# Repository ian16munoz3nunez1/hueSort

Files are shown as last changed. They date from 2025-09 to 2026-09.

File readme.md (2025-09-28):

# HueSort

## Bibliografía y referencias

- [Arduino Documentation](https://docs.arduino.cc/language-reference/)
- [Arduino `abs` function](https://docs.arduino.cc/language-reference/en/functions/math/abs/)
- [Arduino `map` function](https://docs.arduino.cc/language-reference/en/functions/math/map/)
- [`analogWrite` function](https://docs.arduino.cc/language-reference/en/functions/analog-io/analogWrite/)
- [`analogWriteResolution` function](https://docs.arduino.cc/language-reference/en/functions/analog-io/analogWriteResolution/)
- [esp32 repository](https://github.com/espressif/arduino-esp32)
- [esp32 Guidebook](https://espressif-docs.readthedocs-hosted.com/projects/arduino-esp32/en/latest/)
- [esp32 installation guide](https://docs.espressif.com/projects/arduino-esp32/en/latest/installing.html)
- [esp32 PWM](https://randomnerdtutorials.com/esp32-pwm-arduino-ide/)
- [How to create a WiFi Access Point with esp32](https://www.upesy.com/blogs/tutorials/how-create-a-wifi-acces-point-with-esp32#)
- [How do I transfer an image taken by esp32cam over sockets](https://stackoverflow.com/questions/57823528/how-do-i-transfer-an-image-taken-by-esp32-cam-over-sockets)
- [esp32cam ov2640 camera settings](https://randomnerdtutorials.com/esp32-cam-ov2640-camera-settings/)

- [API Pins](https://gpiozero.readthedocs.io/en/stable/api_pins.html)
- [Use GPIO from Python](https://www.raspberrypi.com/documentation/computers/os.html#use-gpio-from-python)
- [Generating PWM in Raspberry Pi](https://forums.raspberrypi.com/viewtopic.php?t=358623)
- [Raspberry Pi y PWM](https://www.prometec.net/raspberry-y-pwm/)
- [FreeRTOS y Raspberry Pi OS](https://forums-raspberrypi-com.translate.goog/viewtopic.php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)

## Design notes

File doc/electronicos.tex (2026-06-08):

\section{Módulo de Sistemas Electrónicos}

\subsection{Componentes utilizados}

{\justify
    \renewcommand{\labelitemi}{$\bullet$}
    \begin{itemize}
        \item Módulo de carga TP4056
        \item Motor CD motorreductor JGA25-370 6V
        \item Regulador de voltaje LM7805
        \item Transistor NPN TIP122
        \item Transistor PNP TIP127
        \item Diodo rectificador 1N4007
    \end{itemize}
}

\subsection{Divisor de voltaje}

{\justify
    \begin{equation*}
        I = \dfrac{V_{in}}{R_1 + R_2} \quad V_d = I R_2
    \end{equation*}

    \begin{equation*}
        V_d = \dfrac{V_{in}}{R_1 + R_2} R_2 \quad\rightarrow\quad V_d = \dfrac{V_{in} R_2}{R_1 + R_2}
    \end{equation*}

    \begin{equation*}
        V_d (R_1 + R_2) = V_{in} R_2 \quad\rightarrow\quad V_d R_1 + V_d R_2 = V_{in} R_2
    \end{equation*}

    \begin{equation*}
        V_d R_1 = V_{in} R_2 - V_d R_2 \quad\rightarrow\quad V_d R_1 = (V_{in} - V_d) R_2
    \end{equation*}

    \begin{equation*}
        R_1 = \dfrac{(V_{in} - V_d) R_2}{V_d} \quad\quad \dfrac{V_d R_1}{V_{in} - V_d} = R_2
    \end{equation*}
}

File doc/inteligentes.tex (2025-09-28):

\section{Módulo de Sistemas Inteligentes}

{\justify
    \hspace{0.5cm} Para el módulo de sistemas inteligentes se utilizó un
    \textbf{Perceptrón Multicapa} para la clasificación de color utilizando el sensor
    \textbf{TCS230} para esto, la red tiene 3 nodos de entrada para realizar la
    clasificación y fue entrenada con 600 muestras diferentes de colores.

    \hspace{0.5cm} Para comenzar, primero veremos el proceso básico utilizado para el
    \textbf{Perceptrón Simple}

}

\subsection{El Perceptrón Simple}
\begin{center}
    \begin{tikzpicture}[scale=0.6]
        \draw (0,4) -- node[above]{$w_1$} (4,0);
        \draw (0,2) -- node[above]{$w_2$} (4,0);
        \draw (0,0) -- node[above]{$w_3$} (4,0);
        \draw (0,-2) -- node[above]{$w_n$} (4,0);
        \draw (0,-4) -- node[above]{$b$} (4,0);
        \draw (4,0) -- node[above]{$v$} (7,0);
        \draw (7,0) -- (9,0);

        \foreach \i in {4,2,...,-4}{\fill[white] (0,\i) circle (5mm);}
        \fill[white] (9,0) circle (5mm);

        \node at (0,4){$x_1$};
        \node at (0,2){$x_2$};
        \node at (0,0){$x_3$};
        \node at (0,-2){$x_n$};
        \node at (0,-4){$+1$};
        \node at (9,0){$y$};

        \draw[color=black,fill=white] (4,0) circle (8mm);
        \node at (4,0){\Large $\sum$};

        \draw[color=black,fill=white] (7,0) circle (6mm);
        \node at (7,0){\Large $\varphi$};
    \end{tikzpicture}
\end{center}

{\justify
    \hspace{0.5cm} Primero de tiene la ecuación en la que interactuan los patrones de
    entrada con los pesos sinápticos y el \textbf{bias}, que se puede representar de
    diferentes formas, como

    \begin{equation}
        v = \sum_{i=1}^p [w_i x_i] + b
    \end{equation}

    \begin{equation}
        v =
        \begin{bmatrix}
            w_1 & w_2 & \cdots & w_p
        \end{bmatrix}
        \begin{bmatrix}
            x_1 \\
            x_2 \\
            \vdots \\
            x_p
        \end{bmatrix} + b
    \end{equation}

    \begin{equation}
        v = w^\top x + b
    \end{equation}

    \hspace{0.5cm} El valor $v$ de esta ecuación se pasa por una función $\phi(v)$ para
    obtener la salida del \textbf{Perceptrón}, que queda representada como

    \begin{equation}
        y = \varphi(v)
    \end{equation}

    \hspace{0.5cm} Después, se obtiene un error con

    \begin{equation}
        e = d - y
    \end{equation}

    \hspace{0.5cm} En dónde $d$ es el valor deseado para el patrón de entrada y $y$ el
    valor obtenido por el perceptrón. Con el valor de $e$ obtenido, se ajustan los pesos
    sinápticos y bias de la siguiente forma

    \begin{align}
        w &\leftarrow w + \eta e x \\
        b &\leftarrow b + \eta e
    \end{align}

    \hspace{0.5cm} En donde $\eta$ es el factor de aprendizaje del perceptrón.
    Con esto, se tiene completado el proceso de aprendizaje del
    \textbf{Perceptrón Simple}. Ahora conociendo esto, podemos avanzar con las ecuaciones
    y el proceso de aprendizaje del \textbf{Perceptrón Mutlicacpa}

}

\subsection{El Perceptrón Multicapa}

\begin{center}
    \begin{tikzpicture}
        \foreach \a in {2,0,-2}{
            \foreach \b in {4,2,...,-4} {
                \foreach \c in {4,2,...,-4}{
                    \foreach \d in {3,1,-1,-3}{
                        \draw[color=magenta, ultra thick] (0,\a)--(4,\b)--(8,\c)--(12,\d);

                    }

                    \fill[blue] (8,\c) circle (5mm);
                }

                \fill[green] (4,\b) circle (5mm);
            }

            \fill[red] (0,\a) circle (3mm);
        }
        \draw[color=magenta, ultra thick] (14,0)--(16,0);
        \fill[cyan] (16,0) circle (3mm);
        \node at (16,0){$y$};

        \node at (0,2){$x_1$};
        \node at (0,0){$x_2$};
        \node at (0,-2){$x_3$};

        \fill[yellow] (12,4) rectangle (14,-4);
        \node at (13,0){\LARGE\rotatebox{90}{Softmax}};
    \end{tikzpicture}
\end{center}

{\justify
}

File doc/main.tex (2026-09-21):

\documentclass[12pt, oneside]{article}
\usepackage[T1]{fontenc}
\usepackage[spanish, es-tabla, es-lcroman]{babel}
\usepackage[utf8]{inputenc}
\usepackage[document]{ragged2e}
\usepackage{tcolorbox}
\tcbuselibrary{theorems}
\usepackage{cancel}
\usepackage{amssymb}
\usepackage{amsmath}
\usepackage{mathrsfs}
\usepackage{wrapfig}
\usepackage{fancyhdr}
\usepackage{colortbl}
\usepackage{diagbox}
\usepackage{longtable}
\usepackage{graphicx}
\usepackage{subcaption}
\usepackage{xcolor}
\usepackage{tikz}
\usetikzlibrary{positioning}
\usepackage{multicol}
\usepackage{multirow}
\usepackage{lastpage}
\usepackage{pdfpages}
\usepackage{listings}
\usepackage{blindtext}
\usepackage{fontawesome}
\usepackage{circuitikz}
\spanishdecimal{.}
\usepackage[explicit]{titlesec}
\usepackage[colorlinks=true, linkcolor=black, citecolor=black, urlcolor=blue]{hyperref}
\usepackage[a4paper, total={16cm , 24cm}]{geometry}
\pagestyle{fancy}
\lhead{CUCEI}
\chead{Hue Sort}
\rhead{Ingeniería Robótica}
\renewcommand{\headrulewidth}{1pt}
\renewcommand{\footrulewidth}{1pt}

\setlength{\headheight}{14.49998pt}

\setlength{\columnseprule}{1pt}
\def\columnseprulecolor{\color{black}}

\begin{document}

\pagenumbering{roman}
\include{portada}

\pagenumbering{arabic}
\include{electronicos}

\include{control}

\include{inteligentes}

\end{document}

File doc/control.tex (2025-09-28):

\section{Cinemática directa}

\subsection{Modelado del \emph{youBot Arm}}

\begin{figure}[h!]
    \centering
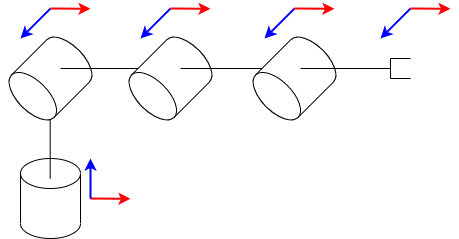
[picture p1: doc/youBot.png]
    
    \caption{\sffamily youBot Arm}
    \label{fig:youBotArmModel}
\end{figure}

\subsection{Fórmulas y propiedades}

\begin{equation*}
    ^{n-1}T_n =
    \begin{bmatrix}
        C_{\theta_n} & -S_{\theta_n}C_{\alpha_n} & S_{\theta_n}S_{\alpha_n} & a_nC_{\theta_n} \\
        S_{\theta_n} & C_{\theta_n}C_{\alpha_n} & -C_{\theta_n}S_{\alpha_n} & a_nS_{\theta_n} \\
        0 & S_{\alpha_n} & C_{\alpha_n} & d_n \\
        0 & 0 & 0 & 1
    \end{bmatrix}
\end{equation*}

\begin{equation*}
    \begin{split}
        \sin(\alpha \pm \beta) & = \sin(\alpha)\cos(\beta) \pm \cos(\alpha)\sin(\beta) \\
        \cos(\alpha \pm \beta) & = \cos(\alpha)\cos(\beta) \mp \sin(\alpha)\sin(\beta)
    \end{split}
\end{equation*}

\newpage
\subsection{Tabla de parámetros \emph{Denavit-Hartenberg}}

\begin{table}[h!]
    \centering\sffamily\large

    \begin{tabular}{|c|c|c|c|c|}
        \hline
        & $\alpha$ & $a$ & $d$ & $\theta$ \\
        \hline
        1 & $\frac{\pi}{2}$ & $0$ & $d_1$ & $0$ \\
        \hline
        2 & $0$ & $a_2$ & $0$ & $0$ \\
        \hline
        3 & $0$ & $a_3$ & $0$ & $0$ \\
        \hline
        4 & $0$ & $a_4$ & $0$ & $0$ \\
        \hline
    \end{tabular}

    \caption{\sffamily Tabla de parámetros \emph{Denavit-Hartenberg}}
    \label{tab:tablaDH}
\end{table}

\subsection{Matrices de transformación}

\begin{equation*}
    \tcboxmath[colback=white, colframe=black]{
    ^0T_1 =
    \begin{bmatrix}
        C_1 & 0 & S_1 & 0 \\
        S_1 & 0 & -C_1 & 0 \\
        0 & 0 & 1 & 0 \\
        0 & 0 & 0 & 1
    \end{bmatrix}
    }
    \quad\quad
    ^1T_2 =
    \begin{bmatrix}
        C_2 & -S_2 & 0 & a_2C_2 \\
        S_2 & C_2 & 0 & a_2S_2 \\
        0 & 0 & 1 & 0 \\
        0 & 0 & 0 & 1
    \end{bmatrix}
\end{equation*}

\begin{equation*}
    ^2T_3 =
    \begin{bmatrix}
        C_3 & -S_3 & 0 & a_3C_3 \\
        S_3 & C_3 & 0 & a_3S_3 \\
        0 & 0 & 1 & 0 \\
        0 & 0 & 0 & 1
    \end{bmatrix}
    \quad\quad
    ^3T_4 =
    \begin{bmatrix}
        C_4 & -S_4 & 0 & a_4C_4 \\
        S_4 & C_4 & 0 & a_4S_4 \\
        0 & 0 & 1 & 0 \\
        0 & 0 & 0 & 1
    \end{bmatrix}
\end{equation*}

\begin{equation*}
    ^0T_4 = {^0T_1} \, {^1T_2} \, {^2T_3} \, {^3T_4}
\end{equation*}

\newpage
\subsection{Cinemática directa del \emph{youBot Arm}}

\begin{equation*}
    \tcboxmath[colback=white, colframe=black]{
    ^0T_2 =
    \begin{bmatrix}
        C_1C_2 & -C_1S_2 & S_1 & a_2C_1C_2 \\
        S_1C_2 & -S_1S_2 & -C_1 & a_2S_1C_2 \\
        S_2 & C_2 & 0 & a_2S_2 + d_1 \\
        0 & 0 & 0 & 1
    \end{bmatrix}
    }
\end{equation*}

{\small
\begin{equation*}
    ^0T_3 =
    \begin{bmatrix}
        C_1C_2C_3 - C_1S_2S_3 & -C_1C_2S_3 - C_1S_2C_3 & S_1 & a_3C_1C_2C_3 - a_3C_1S_2S_3 + a_2C_1C_2 \\
        S_1C_2C_3 - S_1S_2S_3 & -S_1C_2S_3 - S_1S_2C_3 & -C_1 & a_3S_1C_2C_3 - a_3S_1S_2S_3 + a_2S_1C_2 \\
        S_2C_3 + C_2S_3 & -S_2S_3 + C_2C_3 & 0 & a_3S_2C_3 + a_3C_2S_3 + a_2S_2 + d_1 \\
        0 & 0 & 0 & 1
    \end{bmatrix}
\end{equation*}
}

\begin{equation*}
    \tcboxmath[colback=white, colframe=black]{
    ^0T_3 =
    \begin{bmatrix}
        C_1C_{23} & -C_1S_{23} & S_1 & a_3C_1C_{23} + a_2C_1C_2 \\
        S_1C_{23} & -S_1S_{23} & -C_1 & a_3S_1C_{23} + a_2S_1C_2 \\
        S_{23} & C_{23} & 0 & a_3S_{23} + a_2S_2 + d_1 \\
        0 & 0 & 0 & 1
    \end{bmatrix}
    }
\end{equation*}

{\scriptsize
\begin{equation*}
    ^0T_4 =
    \begin{bmatrix}
        C_1C_{23}C_4 - C_1S_{23}S_4 & -C_1C_{23}S_4 - C_1S_{23}C_4 & S_1 & a_4C_1C_{23}C_4 - a_4C_1S_{23}S_4 + a_3C_1C_{23} + a_2C_1C_2 \\
        S_1C_{23}C_4 - S_1S_{23}S_4 & -S_1C_{23}S_4 - S_1S_{23}C_4 & -C_1 & a_4S_1C_{23}C_4 - a_4S_1S_{23}S_4 + a_3S_1C_{23} + a_2S_1C_2 \\
        S_{23}C_4 + C_{23}S_4 & -S_{23}S_4 + C_{23}C_4 & 0 & a_4S_{23}C_4 + a_4C_{23}S_4 + a_3S_{23} + a_2S_2 + d_1 \\
        0 & 0 & 0 & 1
    \end{bmatrix}
\end{equation*}
}

\begin{equation*}
    ^0T_4 =
    \begin{bmatrix}
        C_1C_{234} & -C_1S_{234} & S_1 & a_4C_1C_{234} + a_3C_1C_{23} + a_2C_1C_2 \\
        S_1C_{234} & -S_1S_{234} & -C_1 & a_4S_1C_{234} + a_3S_1C_{23} + a_2C_1C_2 \\
        S_{234} & C_{234} & 0 & a_4S_{234} + a_3S_{23} + a_2S_2 + d_1 \\
        0 & 0 & 0 & 1
    \end{bmatrix}
\end{equation*}

\begin{equation*}
    \tcboxmath[colback=white, colframe=black]{
    ^0T_4 =
    \begin{bmatrix}
        C_1C_{234} & -C_1S_{234} & S_1 & C_1 ( a_4C_{234} + a_3C_{23} + a_2C_2 ) \\
        S_1C_{234} & -S_1S_{234} & -C_1 & S_1 ( a_4C_{234} + a_3C_{23} + a_2C_2 ) \\
        S_{234} & C_{234} & 0 & a_4S_{234} + a_3S_{23} + a_2S_2 + d_1 \\
        0 & 0 & 0 & 1
    \end{bmatrix}
    }
\end{equation*}

\newpage
\subsection{Cinemática directa de la plataforma omnidireccional}

\begin{equation*}
    \begin{bmatrix}
        \dot{x} \\
        \dot{y} \\
        \dot{\theta}
    \end{bmatrix} =
    \begin{bmatrix}
        -\sin(\theta) & \cos(\theta) & L \\
        -\sin(\theta + 120^\circ) & \cos(\theta + 120^\circ) & L \\
        -\sin(\theta + 240^\circ) & \cos(\theta + 240^\circ) & L
    \end{bmatrix}^{-1}
    \begin{bmatrix}
        v_1 \\
        v_2 \\
        v_3
    \end{bmatrix}
\end{equation*}

{\justify
    \hspace{0.5cm} El modelo también se puede representar como

}

\begin{equation*}
    \begin{bmatrix}
        \dot{x} \\
        \dot{y} \\
        \dot{\theta}
    \end{bmatrix} =
    \begin{bmatrix}
        -\sin(\theta) & \cos(\theta) & L \\
        -\sin(\theta + \frac{2\pi}{3}) & \cos(\theta + \frac{2\pi}{3}) & L \\
        -\sin(\theta + \frac{4\pi}{3}) & \cos(\theta + \frac{4\pi}{3}) & L
    \end{bmatrix}^{-1}
    \begin{bmatrix}
        v_1 \\
        v_2 \\
        v_3
    \end{bmatrix}
\end{equation*}

\subsection{Cinemática inversa de la plataforma omnidireccional}

\begin{equation*}
    \begin{bmatrix}
        v_1 \\
        v_2 \\
        v_3
    \end{bmatrix} =
    \begin{bmatrix}
        -\sin(\theta) & \cos(\theta) & L \\
        -\sin(\theta + 120^\circ) & \cos(\theta + 120^\circ) & L \\
        -\sin(\theta + 240^\circ) & \cos(\theta + 240^\circ) & L
    \end{bmatrix}
    \begin{bmatrix}
        \dot{x} \\
        \dot{y} \\
        \dot{\theta}
    \end{bmatrix}
\end{equation*}

{\justify
    \hspace{0.5cm} El modelo también se puede representar como

}

\begin{equation*}
    \begin{bmatrix}
        v_1 \\
        v_2 \\
        v_3
    \end{bmatrix} =
    \begin{bmatrix}
        -\sin(\theta) & \cos(\theta) & L \\
        -\sin(\theta + \frac{2\pi}{3}) & \cos(\theta + \frac{2\pi}{3}) & L \\
        -\sin(\theta + \frac{4\pi}{3}) & \cos(\theta + \frac{4\pi}{3}) & L
    \end{bmatrix}
    \begin{bmatrix}
        \dot{x} \\
        \dot{y} \\
        \dot{\theta}
    \end{bmatrix}
\end{equation*}

\newpage
\subsection{Cinemática directa desde el origen hasta el efector final}

\renewcommand{\labelitemi}{$\bullet$}
\begin{itemize}
    \item \textbf{w:} Eje coordenado del origen.
    \item \textbf{p:} Eje coordenado adherido a la plataforma.
    \item \textbf{b:} Eje coordenado de la base del manipulador.
    \item \textbf{e:} Eje coordenado del actuador final.
\end{itemize}

\begin{equation*}
    ^wT_e = {^wT_p} \, {^pT_b} \, {^bT_e}
\end{equation*}

\begin{equation*}
    \tcboxmath[colback=white, colframe=black]{
    ^wT_p =
    \begin{bmatrix}
        \cos(\theta_p) & -\sin(\theta_p) & 0 & x_p \\
        \sin(\theta_p) & \cos(\theta_p) & 0 & y_p \\
        0 & 0 & 1 & 0 \\
        0 & 0 & 0 & 1
    \end{bmatrix}
    }
\end{equation*}

\hspace{0.5cm} Con $x_p$ y $y_p$ como la posición del robot y $\theta_p$ como la
orientación.

\begin{equation*}
    \tcboxmath[colback=white, colframe=black]{
    ^pT_b =
    \begin{bmatrix}
        1 & 0 & 0 & 0.170 \\
        0 & 1 & 0 & 0 \\
        0 & 0 & 1 & 0.060 \\
        0 & 0 & 0 & 1
    \end{bmatrix}
    }
\end{equation*}

\begin{equation*}
    \tcboxmath[colback=white, colframe=black]{
    ^bT_e = {^0T_4}
    }
\end{equation*}

\begin{equation*}
    \tcboxmath[colback=white, colframe=black]{
    ^wT_b =
    \begin{bmatrix}
        \cos(\theta_p) & -\sin(\theta_p) & 0 & 0.170\cos(\theta_p) + x_p \\
        \sin(\theta_p) & \cos(\theta_p) & 0 & 0.170\sin(\theta_p) + y_p \\
        0 & 0 & 1 & 0.060 \\
        0 & 0 & 0 & 1
    \end{bmatrix}
    }
\end{equation*}

\newpage
{\normalsize
\begin{equation*}
    \tcboxmath[colback=white, colframe=black]{
    \begin{split}
        x & = C_\theta C_1( a_4C_{234}+a_3C_{23}+a_2C_2 ) - S_\theta S_1( a_4C_{234}+a_3C_{23}+a_2C_2 ) + 0.170C_\theta + x_p \\
        y & = S_\theta C_1( a_4C_{234}+a_3C_{23}+a_2C_2 ) + C_\theta S_1( a_4C_{234}+a_3C_{23}+a_2C_2 ) + 0.170S_\theta + y_p \\
        z & = a_4S_{234} + a_3S_{23} + a_2S_2 + d_1 + 0.060 \\
    \end{split}
    }
\end{equation*}
}

{\normalsize
\begin{equation*}
    \tcboxmath[colback=white, colframe=black]{
    ^wT_e =
    \begin{bmatrix}
        C_\theta C_1C_{234} - S_\theta S_1C_{234} & -C_\theta C_1S_{234} + S_\theta S_1S_{234} & C_\theta S_1 + S_\theta C_1 & x \\
        S_\theta C_1 C_{234} + C_\theta S_1C_{234} & -S_\theta C_1S_{234} - C_\theta S_1S_{234} & S_\theta S_1 - C_\theta C_1 & y \\
        S_{234} & C_{234} & 0 & z \\
        0 & 0 & 0 & 1
    \end{bmatrix}
    }
\end{equation*}
}

{\normalsize
\begin{equation*}
    \tcboxmath[colback=white, colframe=black]{
    ^wT_e =
    \begin{bmatrix}
        C_{\theta 1}C_{234} & -C_{\theta 1}S_{234} & S_{\theta 1} & C_{\theta 1} ( a_4C_{234} + a_3C_{23} + a_2C_2 ) + 0.170C_\theta + x_p \\
        S_{\theta 1}C_{234} & -S_{\theta 1}S_{234} & -C_{\theta 1} & S_{\theta 1} ( a_4C_{234} + a_3C_{23} + a_2C_2 ) + 0.170S_\theta + y_p \\
        S_{234} & C_{234} & 0 & a_4S_{234} + a_3S_{23} + a_2S_2 + d_1 + 0.060 \\
        0 & 0 & 0 & 1
    \end{bmatrix}
    }
\end{equation*}
}

\subsection{Cinemática diferencial}

\begin{equation*}
    J_v(q) =
    \begin{bmatrix}
        \dfrac{\partial p_1(q)}{\partial q_1} & \dfrac{\partial p_1(q)}{\partial q_2} & \dotsc & \dfrac{\partial p_1(q)}{\partial q_n} \\
        \dfrac{\partial p_2(q)}{\partial q_1} & \dfrac{\partial p_2(q)}{\partial q_2} & \dotsc & \dfrac{\partial p_2(q)}{\partial q_n} \\
        \vdots & \vdots & \ddots & \vdots \\
        \dfrac{\partial p_m(1)}{\partial q_1} & \dfrac{\partial p_m(q)}{\partial q_2} & \dotsc & \dfrac{\partial p_m(q)}{\partial q_n}
    \end{bmatrix}
\end{equation*}

\begin{equation*}
    \begin{split}
        t_x & = C_{\theta 1} ( a_4C_{234} + a_3C_{23} + a_2C_2 ) + 0.170C_\theta + x_p \\
        t_y & = S_{\theta 1} ( a_4C_{234} + a_3C_{23} + a_2C_2 ) + 0.170S_\theta + y_p \\
        t_z & = a_4S_{234} + a_3S_{23} + a_2S_2 + d_1 + 0.060
    \end{split}
\end{equation*}

\newpage
\begin{equation*}
    \begin{split}
        \frac{\partial t_x}{\partial x_p} & = 1 \\
        \frac{\partial t_x}{\partial y_p} & = 0 \\
        \frac{\partial t_x}{\partial \theta_p} & = -S_{\theta 1} ( a_4C_{234}+a_3C_{23}+a_2C_2 ) - 0.170S_\theta \\
        \frac{\partial t_x}{\partial \theta_1} & = -S_{\theta 1} ( a_4C_{234}+a_3C_{23}+a_2C_2 ) \\
        \frac{\partial t_x}{\partial \theta_2} & = -C_{\theta 1} ( a_4S_{234}+a_3S_{23}+a_2S_2 ) \\
        \frac{\partial t_x}{\partial \theta_3} & = -C_{\theta 1} ( a_4S_{234}+a_3S_{23} ) \\
        \frac{\partial t_x}{\partial \theta_4} & = -a_4C_{\theta 1}S_{234}
    \end{split}
\end{equation*}

\begin{equation*}
    \begin{split}
        \frac{\partial t_y}{\partial x_p} & = 0 \\
        \frac{\partial t_y}{\partial y_p} & = 1 \\
        \frac{\partial t_y}{\partial \theta_p} & = C_{\theta 1} ( a_4C_{234} + a_3C_{23} + a_2C_2 ) + 0.170C_\theta \\
        \frac{\partial t_y}{\partial \theta_1} & = C_{\theta 1} ( a_4C_{234} + a_3C_{23} + a_2C_2 )  \\
        \frac{\partial t_y}{\partial \theta_2} & = -S_{\theta 1} ( a_4S_{234} + a_3S_{23} + a_2S_2 ) \\
        \frac{\partial t_y}{\partial \theta_3} & = -S_{\theta 1} ( a_4S_{234} + a_3S_{23} ) \\
        \frac{\partial t_y}{\partial \theta_4} & = -a_4S_{\theta 1}S_{234}
    \end{split}
\end{equation*}

\newpage
\begin{equation*}
    \begin{split}
        \frac{\partial t_z}{\partial x_p} & = 0 \\
        \frac{\partial t_z}{\partial x_p} & = 0 \\
        \frac{\partial t_z}{\partial x_p} & = 0 \\
        \frac{\partial t_z}{\partial \theta_1} & = 0 \\
        \frac{\partial t_z}{\partial \theta_2} & = a_4C_{234} + a_3C_{23} + a_2C_2 \\
        \frac{\partial t_z}{\partial \theta_3} & = a_4C_{234} + a_3C_{23} \\
        \frac{\partial t_z}{\partial \theta_4} & = a_4C_{234}
    \end{split}
\end{equation*}

\begin{equation*}
    J_v =
    \begin{bmatrix}
        \dfrac{\partial t_x}{\partial x_p} & \dfrac{\partial t_x}{\partial y_p} & \dfrac{\partial t_x}{\partial \theta_p} & \dfrac{\partial t_x}{\partial \theta_1} & \dfrac{\partial t_x}{\partial \theta_2} & \dfrac{\partial t_x}{\partial \theta_3} & \dfrac{\partial t_x}{\partial \theta_4} \\
        \dfrac{\partial t_y}{\partial x_p} & \dfrac{\partial t_y}{\partial y_p} & \dfrac{\partial t_y}{\partial \theta_p} & \dfrac{\partial t_y}{\partial \theta_1} & \dfrac{\partial t_y}{\partial \theta_2} & \dfrac{\partial t_y}{\partial \theta_3} & \dfrac{\partial t_y}{\partial \theta_4} \\
        \dfrac{\partial t_z}{\partial x_p} & \dfrac{\partial t_z}{\partial y_p} & \dfrac{\partial t_z}{\partial \theta_p} & \dfrac{\partial t_z}{\partial \theta_1} & \dfrac{\partial t_z}{\partial \theta_2} & \dfrac{\partial t_z}{\partial \theta_3} & \dfrac{\partial t_z}{\partial \theta_4} \\
    \end{bmatrix}
\end{equation*}

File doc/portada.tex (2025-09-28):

\begin{titlepage}
    \pagenumbering{roman}
    \centering
    {\bfseries\Large Universidad de Guadalajara \par}
    \vfill
    {
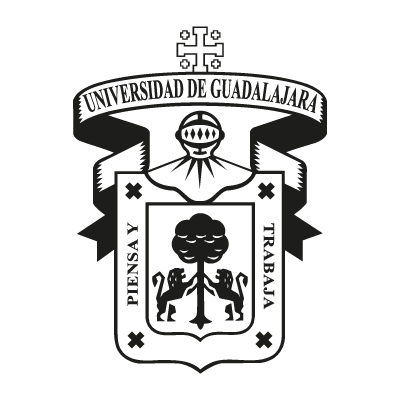
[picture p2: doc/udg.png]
        
        \par
    }
    \vfill
    {\bfseries\Large Centro Universitario de Ciencias Exactas e Ingenierías \par}
    \vfill
    {\bfseries\Large División de Tecnologías para la Integración Ciber-Humana \par}
    \vfill
    {\bfseries\Large Departamento de Innovación Basada en la Información y el Conocimiento \par}
    \vfill
    {\bfseries\Large Título del proyecto \par}
    \vfill
    {\bfseries\Large "Hue-Sort" \par}
    \vfill
    \begin{multicols}{2}
        {\bfseries\Large\raggedleft
            Módulos:

        }

        \columnbreak
        {\bfseries\Large\raggedright
            Sistemas Electrónicos \\
            Sistemas de Control \\
            Sistemas Inteligentes

        }
    \end{multicols}
    \vfill
    \begin{multicols}{2}
        {\raggedleft
            Presenta:

        }

        \columnbreak
        {\raggedright
            Muñoz Nuñez Ian Emmanuel \\
            González Jiménez David Leonardo \\
            Briseño García Edna Elizabeth \\

        }
    \end{multicols} \par
    \vfill
    \begin{multicols}{2}
        {\raggedleft
            Asesora:

        }

        \columnbreak
        {\raggedright
            Dra. Alma Yolanda Alanís García

        }
    \end{multicols}
\end{titlepage}

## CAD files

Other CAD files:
3d/arm/arm.blend
3d/arm/servo_lever.blend
3d/base.blend
3d/bat_case.blend
3d/bottom_case.blend
3d/pin.blend
3d/top_case.blend
3d/top_cover.blend
3d/wheels/adapter.blend
3d/wheels/motor_support.blend

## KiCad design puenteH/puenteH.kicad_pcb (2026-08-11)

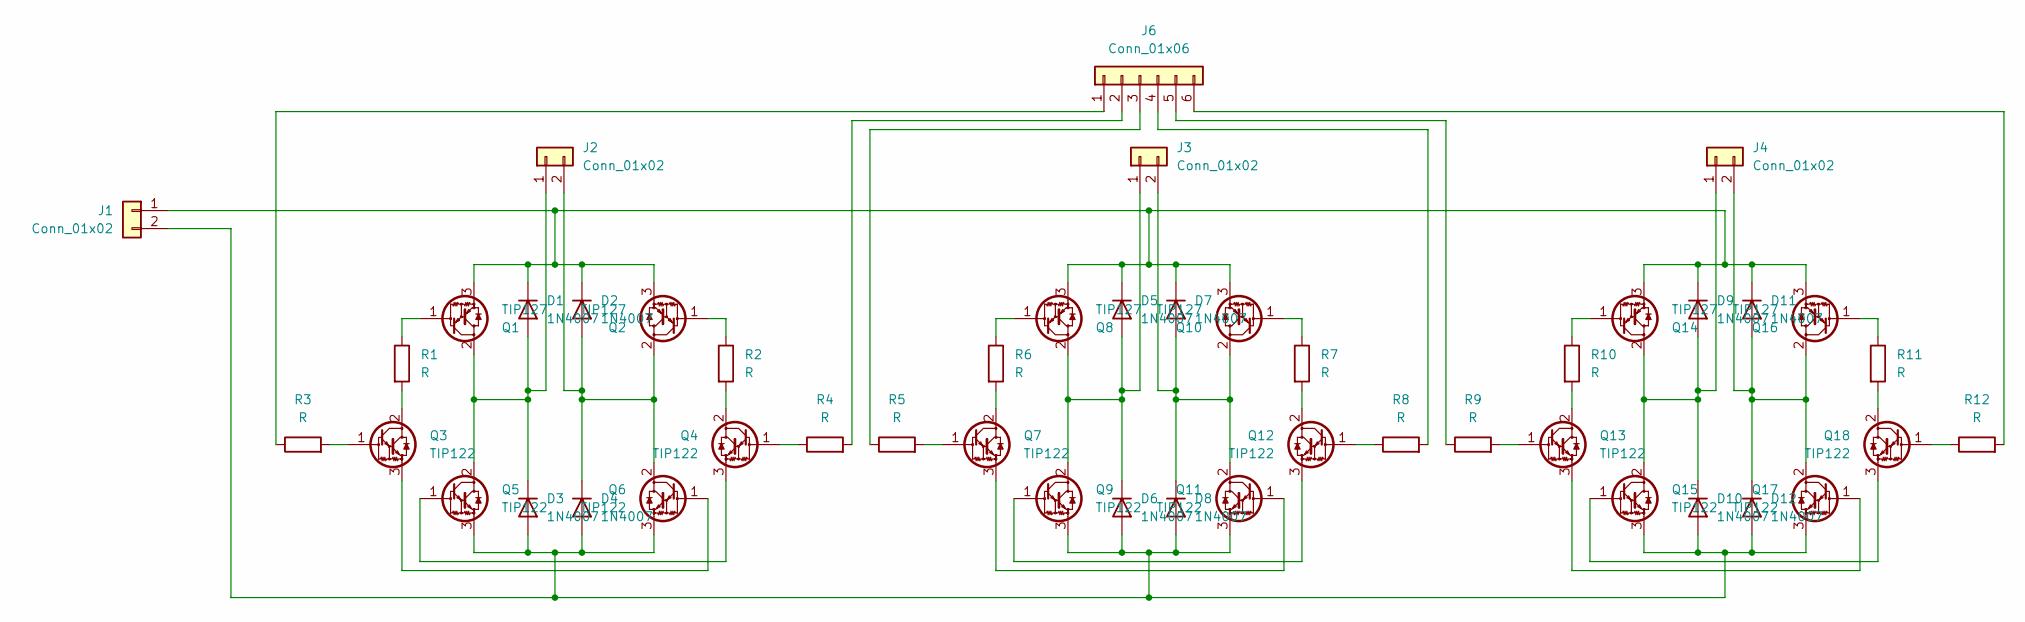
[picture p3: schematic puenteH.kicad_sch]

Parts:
D1, D2, D3, D4, D5, D6, D7, D8, D9, D10, D11, D12: 1N4007; D_DO-41_SOD81_P10.16mm_Horizontal
J1, J2, J3, J4: Conn_01x02; TerminalBlock_bornier-2_P5.08mm
J6: Conn_01x06; TerminalBlock_bornier-6_P5.08mm
Q1, Q2, Q8, Q10, Q14, Q16: TIP127; TO-220-3_Horizontal_TabDown
Q3, Q4, Q5, Q6, Q7, Q9, Q11, Q12, Q13, Q15, Q17, Q18: TIP122; TO-220-3_Horizontal_TabDown
R1, R2, R3, R4, R5, R6, R7, R8, R9, R10, R11, R12: R; R_Axial_DIN0207_L6.3mm_D2.5mm_P10.16mm_Horizontal

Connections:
unnamed: D1.2 (A), D3.1 (K), J2.1, Q1.2 (C), Q5.2 (C)
unnamed: D1.1 (K), D2.1 (K), D5.1 (K), D7.1 (K), D9.1 (K), D11.1 (K), J1.1, Q1.3 (E), Q2.3 (E), Q8.3 (E), Q10.3 (E), Q14.3 (E), Q16.3 (E)
unnamed: D2.2 (A), D4.1 (K), J2.2, Q2.2 (C), Q6.2 (C)
unnamed: D5.2 (A), D6.1 (K), J3.1, Q8.2 (C), Q9.2 (C)
unnamed: D7.2 (A), D8.1 (K), J3.2, Q10.2 (C), Q11.2 (C)
unnamed: D3.2 (A), D4.2 (A), D6.2 (A), D8.2 (A), D10.2 (A), D12.2 (A), J1.2, Q5.3 (E), Q6.3 (E), Q9.3 (E), Q11.3 (E), Q15.3 (E), Q17.3 (E)
unnamed: D9.2 (A), D10.1 (K), J4.1, Q14.2 (C), Q15.2 (C)
unnamed: D11.2 (A), D12.1 (K), J4.2, Q16.2 (C), Q17.2 (C)
unnamed: J6.1, R3.1
unnamed 10: J6.2, R4.2; also elsewhere on the board
unnamed 11: J6.3, R5.1; also elsewhere on the board
unnamed 12: J6.4, R8.2; also elsewhere on the board
unnamed 13: J6.5, R9.1; also elsewhere on the board
unnamed 14: J6.6, R12.2; also elsewhere on the board
unnamed: Q1.1 (B), R1.1
unnamed: Q2.1 (B), R2.1
unnamed 17: Q3.1 (B), R3.2; also elsewhere on the board
unnamed: Q3.2 (C), R1.2
unnamed: Q3.3 (E), Q6.1 (B)
unnamed: Q4.1 (B), R4.1
unnamed: Q4.2 (C), R2.2
unnamed: Q4.3 (E), Q5.1 (B)
unnamed: Q7.1 (B), R5.2
unnamed: Q7.2 (C), R6.2
unnamed: Q8.1 (B), R6.1
unnamed: Q10.1 (B), R7.1
unnamed: Q7.3 (E), Q11.1 (B)
unnamed: Q12.1 (B), R8.1
unnamed: Q12.2 (C), R7.2
unnamed: Q9.1 (B), Q12.3 (E)
unnamed: Q13.1 (B), R9.2
unnamed: Q13.2 (C), R10.2
unnamed: Q13.3 (E), Q17.1 (B)
unnamed: Q14.1 (B), R10.1
unnamed: Q15.1 (B), Q18.3 (E)
unnamed: Q16.1 (B), R11.1
unnamed: Q18.1 (B), R12.1
unnamed: Q18.2 (C), R11.2

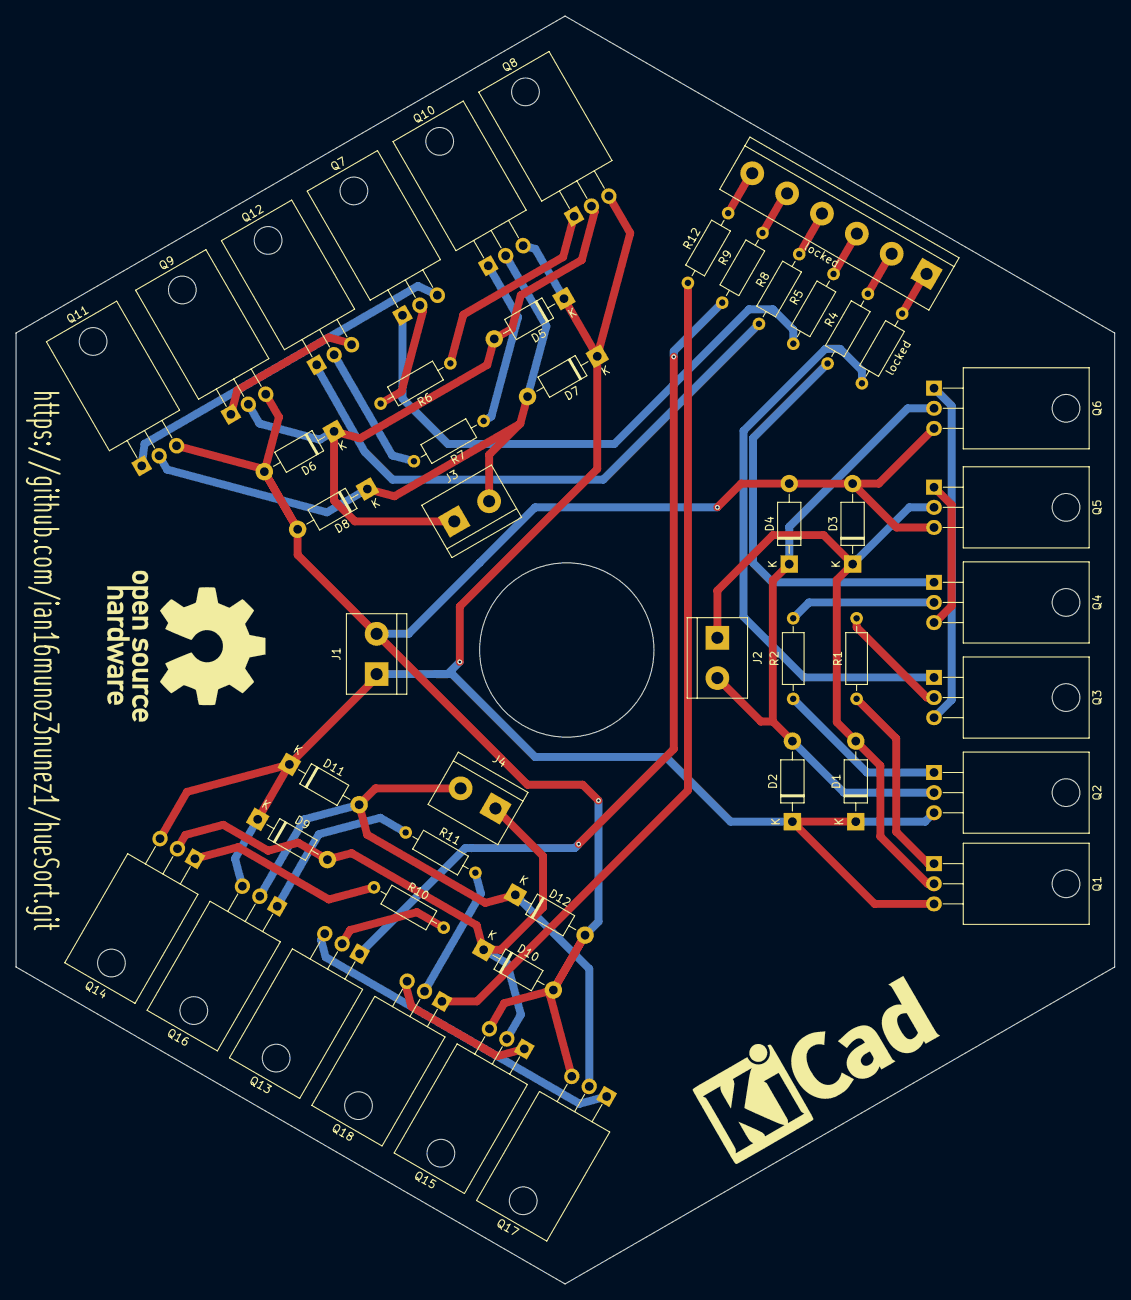
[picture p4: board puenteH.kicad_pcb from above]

Board: 2 copper layers, 138.6 x 160.0 mm, 47 parts (0 on the bottom side), 38 nets.

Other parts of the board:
locked: Conn_01x06; TerminalBlock_bornier-6_P5.08mm
locked#2: locked; R_Axial_DIN0207_L6.3mm_D2.5mm_P10.16mm_Horizontal

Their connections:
unnamed: locked.1, locked#2.1
unnamed 10: locked.2; also elsewhere on the board
unnamed 11: locked.3; also elsewhere on the board
unnamed 12: locked.4; also elsewhere on the board
unnamed 13: locked.5; also elsewhere on the board
unnamed 14: locked.6; also elsewhere on the board
unnamed 17: locked#2.2; also elsewhere on the board

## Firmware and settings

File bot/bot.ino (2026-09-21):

#include <WiFi.h>
#include "led.h"
#include "motor.h"

NetworkServer server(9999);

void bot(NetworkClient);

Led led0(2);
Motor motor1(32, 33);
Motor motor2(25, 26);
Motor motor3(14, 12);

const char* ssid = "rpinet";
const char* password = "rp1_N37!";

IPAddress ip(4,4,0,32);
IPAddress gateway(4,4,0,1);
IPAddress subnet(255,255,255,0);

void setup()
{
  WiFi.mode(WIFI_STA);
  WiFi.config(ip, gateway, subnet);
  WiFi.begin(ssid, password);
  led0.blink(2, 200);

  while(WiFi.status() != WL_CONNECTED) { led0.blink(1, 2000); }
  led0.blink(3, 200);

  // Serial.begin(115200);
  // Serial.println("");
  // Serial.println("WiFi connected!!");
  // Serial.print("IP Address: ");
  // Serial.println(WiFi.localIP());

  server.begin();
}

void loop()
{
  NetworkClient client = server.accept();

  if(client)
  {
    // Serial.println("New Client Connected");
    bot(client);
  }

  led0.blink(1, 500);
}

void bot(NetworkClient client)
{
  String velocidad1, velocidad2, velocidad3;
  int v1, v2, v3;
  
  while(client.connected())
  {
    if(client.available())
    {
      String msg = client.readStringUntil('\n');

      if(msg == "q") break;

      velocidad1 = msg.substring(0,4);
      velocidad2 = msg.substring(4,8);
      velocidad3 = msg.substring(8,12);

      v1 = velocidad1.toInt();
      v2 = velocidad2.toInt();
      v3 = velocidad3.toInt();

      motor1.setVelocity(v1);
      motor2.setVelocity(v2);
      motor3.setVelocity(v3);
    }
  }
  client.stop();
  // Serial.println("Client Disconnected");

  motor1.stop();
  motor2.stop();
  motor3.stop();

  led0.blink(4, 500);
}

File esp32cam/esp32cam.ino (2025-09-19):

#include "esp_camera.h"
#include <WiFi.h>
#include <WiFiClient.h>
#include <WiFiServer.h>

// WiFi credentials
const char* ssid = "";
const char* password = "";

// TCP server on the specified port
WiFiServer server(10001);

// IP address configuration
IPAddress ip(192,168,1,101);
IPAddress gateway(192,168,1,1);
IPAddress subnet(255,255,255,0);

// Camera configuration for AI-Thinker ESP32-CAM
#define PWDN_GPIO_NUM     32
#define RESET_GPIO_NUM    -1
#define XCLK_GPIO_NUM      0
#define SIOD_GPIO_NUM     26
#define SIOC_GPIO_NUM     27
#define Y9_GPIO_NUM       35
#define Y8_GPIO_NUM       34
#define Y7_GPIO_NUM       39
#define Y6_GPIO_NUM       36
#define Y5_GPIO_NUM       21
#define Y4_GPIO_NUM       19
#define Y3_GPIO_NUM       18
#define Y2_GPIO_NUM        5
#define VSYNC_GPIO_NUM    25
#define HREF_GPIO_NUM     23
#define PCLK_GPIO_NUM     22

void setup() {
  // Serial.begin(115200);
  // Serial.setDebugOutput(true);

  // Initialize camera
  camera_config_t config;
  config.ledc_channel = LEDC_CHANNEL_0;
  config.ledc_timer = LEDC_TIMER_0;
  config.pin_d0 = Y2_GPIO_NUM;
  config.pin_d1 = Y3_GPIO_NUM;
  config.pin_d2 = Y4_GPIO_NUM;
  config.pin_d3 = Y5_GPIO_NUM;
  config.pin_d4 = Y6_GPIO_NUM;
  config.pin_d5 = Y7_GPIO_NUM;
  config.pin_d6 = Y8_GPIO_NUM;
  config.pin_d7 = Y9_GPIO_NUM;
  config.pin_xclk = XCLK_GPIO_NUM;
  config.pin_pclk = PCLK_GPIO_NUM;
  config.pin_vsync = VSYNC_GPIO_NUM;
  config.pin_href = HREF_GPIO_NUM;
  config.pin_sscb_sda = SIOD_GPIO_NUM;
  config.pin_sscb_scl = SIOC_GPIO_NUM;
  config.pin_pwdn = PWDN_GPIO_NUM;
  config.pin_reset = RESET_GPIO_NUM;
  config.xclk_freq_hz = 20000000;
  config.pixel_format = PIXFORMAT_JPEG;

  // Lower resolution for better streaming performance
  config.frame_size = FRAMESIZE_VGA;  // 640x480
  config.jpeg_quality = 12;
  config.fb_count = 1;

  // Initialize camera
  esp_err_t err = esp_camera_init(&config);
  if (err != ESP_OK) {
    // Serial.printf("Camera init failed with error 0x%x", err);
    return;
  }

  // Connect to WiFi
  WiFi.mode(WIFI_STA);
  WiFi.config(ip, gateway, subnet);
  WiFi.begin(ssid, password);
  while (WiFi.status() != WL_CONNECTED) { delay(500); }

  // Start TCP server
  server.begin();
}

void loop() {
  WiFiClient client = server.available();

  if (client) {
    while (client.connected()) {
      // Take a picture
      camera_fb_t *fb = esp_camera_fb_get();
      if (!fb) { break; }

      // Send the image size
      uint32_t frame_size = fb->len;
      client.write((uint8_t*)&frame_size, 4);

      // Send the image data
      size_t sent = 0;
      while (sent < fb->len) {
        size_t chunk_size = min((size_t)1024, fb->len - sent);
        size_t bytes_written = client.write(fb->buf + sent, chunk_size);
        if (bytes_written == 0) { break; }
        sent += bytes_written;
      }

      // Free space to reuse memory address
      esp_camera_fb_return(fb);
      delay(100);
    }

    client.stop();
  }
}

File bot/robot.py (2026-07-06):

import socket
import errno
import numpy as np
import os

pi = np.pi
L = 0.08
p_b = [0.07, 0.0, 0.085]
a = [0, 0.05, 0.05]
d = [0, 0, 0]
x_t, y_t, z_t = p_b


class Robot:
    def __init__(self):
        if not os.path.isdir("./data/"):
            os.mkdir("./data/")

        q_file = "./data/q.csv"
        qd_file = "./data/q_dot.csv"
        xd_file = "./data/x_d.csv"
        e_file = "./data/e.csv"
        v_file = "./data/v.csv"
        x_file = "./data/x.csv"

        self.q_plot = open(q_file, 'a')
        self.qd_plot = open(qd_file, 'a')
        self.xd_plot = open(xd_file, 'a')
        self.e_plot = open(e_file, 'a')
        self.v_plot = open(v_file, 'a')
        self.x_plot = open(x_file, 'a')

        if os.path.getsize(q_file) == 0:
            self.q_plot.write("t,x_b,y_b,theta_b,theta_2,theta_3\n")
        if os.path.getsize(qd_file) == 0:
            self.qd_plot.write("t,x_b,y_b,theta_b,theta_2,theta_3\n")
        if os.path.getsize(xd_file) == 0:
            self.xd_plot.write("t,x_b,y_b,theta_b,x,y,z\n")
        if os.path.getsize(e_file) == 0:
            self.e_plot.write("t,x_b,y_b,theta_b,x,y,z\n")
        if os.path.getsize(v_file) == 0:
            self.v_plot.write("t,v_1,v_2,v_3\n")
        if os.path.getsize(x_file) == 0:
            self.x_plot.write("t,x,y,z\n")

    def connect(self, host: str, port: int):
        self.sock = socket.socket(socket.AF_INET, socket.SOCK_STREAM)
        self.sock.setsockopt(socket.SOL_SOCKET, socket.SO_REUSEADDR, 1)
        status = self.sock.connect_ex((host, port))

        if status > 0:
            if status == errno.ECONNREFUSED:
                raise ValueError("Connection refused")

            elif status == errno.ETIMEDOUT:
                raise ValueError("Connection timeout")

            else:
                raise ValueError(f"Error connecting - errno: {status}")
        print("Successfully connected")

    def disconnect(self):
        self.sock.close()
        print("Robot disconnected")

        self.q_plot.close()
        print("File q.csv closed")
        self.qd_plot.close()
        print("File q_dot.csv closed")
        self.xd_plot.close()
        print("File x_d.csv closed")
        self.e_plot.close()
        print("File e.csv closed")
        self.v_plot.close()
        print("File v.csv closed")
        self.x_plot.close()
        print("File x.csv closed")

    def writeHome(self):
        q = np.array([0, 0, 0, pi/4, -pi/4])

        with open("./data/pose.dat", 'w') as pose:
            for i in range(5):
                pose.write(f"{q[i]}\n")
        pose.close()

    def writePose(self, q):
        with open("./data/pose.dat", 'w') as pose:
            for i in range(5):
                pose.write(f"{q[i]}\n")
        pose.close()

    def readPose(self):
        try:
            q = np.ndarray((5,), dtype=np.float64)
            with open("./data/pose.dat", 'r') as pose:
                for i in range(5):
                    q[i] = np.float64(pose.readline())
            pose.close()

        except Exception as e:
            print(f"Unable to read pose from file: {e}")
            q = np.array([0, 0, 0, pi/4, -pi/4])

        print("==== Pose ==== ")
        print(f"x: {q[0]}")
        print(f"y: {q[1]}")
        print(f"theta: {q[2]}")
        print(f"theta_2: {q[3]}")
        print(f"theta_3: {q[4]}")
        print("==== Pose ==== ")

        return q

    def setJointVelocity(self, v: [float]):
        l, h = -10000, 10000
        lim = 100
        v = (l + (h - l)) * v
        v = np.minimum(v, np.array([lim, lim, lim]))
        v = np.maximum(v, np.array([-lim, -lim, -lim]))
        v = ''.join([str(int(x)).zfill(4) for x in v])
        self.sock.send(v.encode('utf-8'))

    def setVelocity(self, v: [float]):
        v = ''.join([str(x).zfill(4) for x in v])

        try:
            self.sock.send(v.encode('utf-8'))
            return True

        except Exception:
            return False

    def matrix(self, q: [float]):
        m = np.array([[-np.sin(q[2]), np.cos(q[2]), L],
                      [-np.sin(q[2] + (2*pi)/3), np.cos(q[2] + (2*pi)/3), L],
                      [-np.sin(q[2] + (4*pi)/3), np.cos(q[2] + (4*pi)/3), L]])

        return m

    def wTe(self, q: np.ndarray) -> np.ndarray:
        t11 = np.cos(q[2])*np.cos(q[3] + q[4])
        t21 = np.sin(q[2])*np.cos(q[3] + q[4])
        t31 = np.sin(q[3] + q[4])
        t41 = 0

        t12 = -np.cos(q[2])*np.sin(q[3] + q[4])
        t22 = -np.sin(q[2])*np.sin(q[3] + q[4])
        t32 = np.cos(q[3] + q[4])
        t42 = 0

        t13 = -np.sin(q[2])
        t23 = np.cos(q[2])
        t33 = 0
        t43 = 0

        t14 = q[0] + x_t*np.cos(q[2]) - y_t*np.sin(q[2]) + np.cos(q[2])*(a[1]*np.cos(q[3]) + a[2]*np.cos(q[3] + q[4]))
        t24 = q[1] + x_t*np.sin(q[2]) + y_t*np.cos(q[2]) + np.sin(q[2])*(a[1]*np.cos(q[3]) + a[2]*np.cos(q[3] + q[4]))
        t34 = z_t + d[0] + a[1]*np.sin(q[3]) + a[2]*np.sin(q[3]+q[4])
        t44 = 1

        wte = np.array([[t11, t12, t13, t14],
                        [t21, t22, t23, t24],
                        [t31, t32, t33, t34],
                        [t41, t42, t43, t44]], dtype=np.float64)
        return wte

    def j_v(self, q: np.ndarray) -> np.ndarray:
        t11, t21, t31 = 1, 0, 0
        t12, t22, t32 = 0, 1, 0

        t13 = -x_t*np.sin(q[2]) - y_t*np.cos(q[2]) - np.sin(q[2])*(a[1]*np.cos(q[3])+a[2]*np.cos(q[3]+q[4]))
        t23 = x_t*np.cos(q[2]) - y_t*np.sin(q[2]) + np.cos(q[2])*(a[1]*np.cos(q[3])+a[2]*np.cos(q[3]+q[4]))
        t33 = 0

        t14 = -a[1]*np.cos(q[2])*np.sin(q[3]) - a[2]*np.cos(q[2])*np.sin(q[3]+q[4])
        t24 = -a[1]*np.sin(q[2])*np.sin(q[3]) - a[2]*np.sin(q[2])*np.sin(q[3]+q[4])
        t34 = a[1]*np.cos(q[3]) + a[2]*np.cos(q[3]+q[4])

        t15 = -a[2]*np.cos(q[2])*np.sin(q[3]+q[4])
        t25 = -a[2]*np.sin(q[2])*np.sin(q[3]+q[4])
        t35 = a[2]*np.cos(q[3]+q[4])

        jacob = np.array([[t11, t12, t13, t14, t15],
                          [t21, t22, t23, t24, t25],
                          [t31, t32, t33, t34, t35]], dtype=np.float64)
        return jacob

    def go2(self, t: float, n: int, q: np.ndarray((5,), dtype=np.float64),
            k: np.ndarray((3, 3), dtype=np.float64),
            x_d: np.ndarray((3,), dtype=np.float64)):
        q_dot = np.array([0, 0, 0, 0, 0], dtype=np.float64)

        try:
            with open("./data/last_time.dat", 'r') as file:
                last = np.float64(file.readline())
            file.close()

        except Exception:
            last = 0

        i = 0
        while i < n:
            try:
                e = x_d - q[:3]
                self.e_plot.write(f"{last + (i*t)},{e[0]},{e[1]},{e[2]},0,0,0\n")
                if np.abs(np.mean(e)) < 1e-4:
                    break
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

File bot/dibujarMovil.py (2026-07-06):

import numpy as np
import matplotlib.pyplot as plt


def dibujarMovil(L, q: [float], p_b: [float], a: [float], d: [float],
                 x_plot: np.ndarray = None):
    x = q[0]
    y = q[1]
    theta = q[2]
    x_t, y_t, z_t = p_b
    pi = np.pi

    ax = plt.axes(projection='3d')
    ax.axis('equal')
    ax.grid(True)
    lim = 0.8
    ax.set_xlim([-lim, lim])
    ax.set_ylim([-lim, lim])
    ax.set_zlim([-lim, lim])
    ax.set_xlabel('x')
    ax.set_ylabel('y')
    ax.set_zlabel('z')
    ax.plot(x, y, 'yo', linewidth=3, markersize=5)

    Lo = L*0.1
    lo = L*0.2
    r_z1 = np.array([[np.cos(theta), -np.sin(theta), x],
                    [np.sin(theta), np.cos(theta), y],
                    [0, 0, 1]])
    r_z2 = np.array([[np.cos(theta+2*(pi/3)), -np.sin(theta+2*(pi/3)), x],
                    [np.sin(theta+2*(pi/3)), np.cos(theta+2*(pi/3)), y],
                    [0, 0, 1]])
    r_z3 = np.array([[np.cos(theta+4*(pi/3)), -np.sin(theta+4*(pi/3)), x],
                    [np.sin(theta+4*(pi/3)), np.cos(theta+4*(pi/3)), y],
                    [0, 0, 1]])
    w1 = np.array([[1, 0, L],
                   [0, 1, 0],
                   [0, 0, 1]])
    w2 = np.array([[1, 0, L],
                   [0, 1, 0],
                   [0, 0, 1]])
    w3 = np.array([[1, 0, L],
                   [0, 1, 0],
                   [0, 0, 1]])
    w1 = np.matmul(r_z1, w1)
    w2 = np.matmul(r_z2, w2)
    w3 = np.matmul(r_z3, w3)

    # Base
    phi = np.linspace(0, 2*pi, 50)

    cx = x + (L-Lo)*np.cos(phi)
    cy = y + (L-Lo)*np.sin(phi)
    ax.plot(cx, cy, 'c', linewidth=4)

    # Ruedas
    p1 = np.dot(w1, np.array([+Lo, -lo, 1]).reshape(-1, 1))
    p2 = np.dot(w1, np.array([-Lo, -lo, 1]).reshape(-1, 1))
    p3 = np.dot(w1, np.array([+Lo, +lo, 1]).reshape(-1, 1))
    p4 = np.dot(w1, np.array([-Lo, +lo, 1]).reshape(-1, 1))
    ax.plot([p1[0], p2[0]], [p1[1], p2[1]], 'b-', linewidth=4)
    ax.plot([p1[0], p3[0]], [p1[1], p3[1]], 'b-', linewidth=4)
    ax.plot([p2[0], p4[0]], [p2[1], p4[1]], 'b-', linewidth=4)
    ax.plot([p3[0], p4[0]], [p3[1], p4[1]], 'b-', linewidth=4)

    p1 = np.dot(w2, np.array([+Lo, -lo, 1]).reshape(-1, 1))
    p2 = np.dot(w2, np.array([-Lo, -lo, 1]).reshape(-1, 1))
    p3 = np.dot(w2, np.array([+Lo, +lo, 1]).reshape(-1, 1))
    p4 = np.dot(w2, np.array([-Lo, +lo, 1]).reshape(-1, 1))
    ax.plot([p1[0], p2[0]], [p1[1], p2[1]], 'b-', linewidth=4)
    ax.plot([p1[0], p3[0]], [p1[1], p3[1]], 'b-', linewidth=4)
    ax.plot([p2[0], p4[0]], [p2[1], p4[1]], 'b-', linewidth=4)
    ax.plot([p3[0], p4[0]], [p3[1], p4[1]], 'b-', linewidth=4)

    p1 = np.dot(w3, np.array([+Lo, -lo, 1]).reshape(-1, 1))
    p2 = np.dot(w3, np.array([-Lo, -lo, 1]).reshape(-1, 1))
    p3 = np.dot(w3, np.array([+Lo, +lo, 1]).reshape(-1, 1))
    p4 = np.dot(w3, np.array([-Lo, +lo, 1]).reshape(-1, 1))
    ax.plot([p1[0], p2[0]], [p1[1], p2[1]], 'b-', linewidth=4)
    ax.plot([p1[0], p3[0]], [p1[1], p3[1]], 'b-', linewidth=4)
    ax.plot([p2[0], p4[0]], [p2[1], p4[1]], 'b-', linewidth=4)
    ax.plot([p3[0], p4[0]], [p3[1], p4[1]], 'b-', linewidth=4)

    # Manipulador
    wt1 = np.array([[np.cos(theta), 0, -np.sin(theta), x_t*np.cos(theta) - y_t*np.sin(theta) + x],
                    [np.sin(theta), 0, np.cos(theta), x_t*np.sin(theta) + y_t*np.cos(theta) + y],
                    [0, 1, 0, z_t + d[0]],
                    [0, 0, 0, 1]], dtype=np.float64)
    ax.plot3D(wt1[0, 3], wt1[1, 3], wt1[2, 3], 'ko')

    wt2 = np.array([[np.cos(theta)*np.cos(q[3]), -np.cos(theta)*np.sin(q[3]), -np.sin(theta), x + x_t*np.cos(theta) - y_t*np.sin(theta) + a[1]*np.cos(theta)*np.cos(q[3])],
                    [np.sin(theta)*np.cos(q[3]), -np.sin(theta)*np.sin(q[3]), np.cos(theta), y + x_t*np.sin(theta) + y_t*np.cos(theta) + a[1]*np.sin(theta)*np.cos(q[3])],
                    [np.sin(q[3]), np.cos(q[3]), 0, z_t + d[0] + a[1]*np.sin(q[3])],
                    [0, 0, 0, 1]], dtype=np.float64)
    ax.plot3D(wt2[0, 3], wt2[1, 3], wt2[2, 3], 'ko')
    ax.plot3D([wt1[0, 3], wt2[0, 3]], [wt1[1, 3], wt2[1, 3]], [wt1[2, 3], wt2[2, 3]], 'k-', linewidth=2)

    t11 = np.cos(q[2])*np.cos(q[3]+q[4])
    t21 = np.sin(q[2])*np.cos(q[3]+q[4])
    t31 = np.sin(q[3]+q[4])
    t41 = 0

    t12 = -np.cos(q[2])*np.sin(q[3]+q[4])
    t22 = -np.sin(q[2])*np.sin(q[3]+q[4])
    t32 = np.cos(q[3]+q[4])
    t42 = 0

    t13 = -np.sin(q[2])
    t23 = np.cos(q[2])
    t33 = 0
    t43 = 0

    t14 = x + x_t*np.cos(q[2]) - y_t*np.sin(q[2]) + np.cos(q[2])*(a[1]*np.cos(q[3]) + a[2]*np.cos(q[3]+q[4]))
    t24 = y + x_t*np.sin(q[2]) + y_t*np.cos(q[2]) + np.sin(q[2])*(a[1]*np.cos(q[3]) + a[2]*np.cos(q[3]+q[4]))
    t34 = z_t + d[0] + a[1]*np.sin(q[3]) + a[2]*np.sin(q[3]+q[4])
    t44 = 1

    wte = np.array([[t11, t12, t13, t14],
                    [t21, t22, t23, t24],
                    [t31, t32, t33, t34],
                    [t41, t42, t43, t44]], dtype=np.float64)
    ax.plot3D([wt2[0, 3], wte[0, 3]], [wt2[1, 3], wte[1, 3]], [wt2[2, 3], wte[2, 3]], 'k-', linewidth=2)

    if x_plot is not None:
        ax.plot3D(x_plot[0, 1:], x_plot[1, 1:], x_plot[2, 1:], 'y-', linewidth=2)

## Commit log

2025-08-25 Base requirements
    - 3D models to print
    - C and Python code for bot controlling
    - esp32cam application
    - MLP implementation to color recognition
    - Access Point for private network
    - Simulation to understand the project functionality
    [adapter.blend, base.blend]
2025-09-19 bot and esp32cam files updated
2025-09-28 readme.md y documento
    - Nuevas referencias agregadas al archivo readme.md
    - Inicio de documentacion
2026-02-19 Base and pin blend files added to repo
    [base.blend, pin.blend]
2026-03-01 Modulo de eletronica y divisor de voltaje agregados a doc
2026-04-11 Changes in files for esp32 functionality
    - Deleted lines for print messages in motor.cpp file
    - PWM ranges for velocities changed in motor.cpp file
    - Last lines deleted in bot.ino, led.cpp and motor.cpp
    files
    - test.py file deleted, a new file will be added
2026-05-31 3D models printed and tested successfully
    [adapter.blend, base.blend, bottom_case.blend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]
2026-06-08 bot/bot.ino file updated
    - Motor pins changed
    - Wi-Fi network updated to the Raspberry Pi one
    - IP addresses changed to the Raspberry Pi subnet
2026-06-08 H-Bridge design with KiCad added to repo
    [puenteH.kicad_pcb, puenteH.kicad_sch]
2026-06-17 Motor support design added to repo
    [motor_support.blend]
2026-06-30 Lever design for servo motor added to repo
    [servo_lever.blend]
2026-07-05 Blender files for motor and wheels moved to wheels/ folder
    [adapter.blend, motor_support.blend]
2026-07-06 Variables de estado del robot y trayectorias guardadas en archivos
    Las variables como q, q_dot, e, v, x_d y x se guardan ahora en
    archivos para poder ver la información de las trayectorias y
    el control de manera más optima
    También se agregaron los archivos ./bot/data/pose.dat para
    guardar la pose del robot y ./bot/data/last_time.dat para
    guardar el último punto de la simulación, para hacer gráficas
    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
    [e.csv, q.csv, q_dot.csv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]
2026-08-11 Schematic and PCB design finished
    [puenteH.kicad_pcb, puenteH.kicad_sch]
2026-09-21 New 3D models version
    [bottom_case.blend, top_case.blend, top_cover.blend]
2026-09-21 Arm 3D models added to repo
    [arm.blend, servo_lever.blend]
2026-09-21 3D battery case model added to repo
    [bat_case.blend]
2026-09-21 blinking for esp32 during Wi-Fi connection
2026-09-21 Color data capture
    The color data capture code implemented to get the values
    from the tcs230 color sensor and save them in a .csv file
2026-09-21 Files for robot arm control added to repo
